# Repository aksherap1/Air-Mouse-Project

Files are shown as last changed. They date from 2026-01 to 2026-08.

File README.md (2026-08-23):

# Air Mouse Project

Screenshot 2026-01-02 at 2 03 32 PM

Screenshot 2026-08-23 at 3 50 18 PM

### About  
The Air Mouse is a wireless, motion-controlled computer mouse. Using an ESP32 microcontroller and an MPU-6050 IMU sensor, it detects hand movement and translates it into cursor movement on your computer. A push button allows for left-click functionality.  

This project demonstrates:

- Bluetooth HID communication
- Sensor integration
- Embedded programming w/Arduino IDE
- PCB Building
- Gyroscope + accelerometer processing
- Motion-controlled input devices
- Button input handling
- Real-time data processing
- Adjustable sensitivity & deadzone implementation

---

### Materials Used  

- ESP32 Nano Dev Board
- MPU-6050
- 4 Push Buttons
- Breadboard
- Jumper Wires
- USB Cable
- PCB

---

### Process

**1. Set up development environment**
- Install Arduino IDE
- Add ESP32 board support
- Install ESP32-BLE-Mouse library by T-vK

**2. Connect hardware (Breadboard)**
- Wire MPU-6050 to ESP32 via I2C (SDA -> ESP32 Nano D13, SCL -> ESP32 Nano D12, VCC -> 3.3V, GND -> GND)
- Connect push button to a digital input pin (e.g., D5, D6, D7, D8) & connect the other terminal to GND
- Use a breadboard for easy prototyping

**3. Test BLE Mouse**
- Open: File -> Examples ->ESP32 BLE Mouse -> BLE_Mouse in Arduino IDE
- Upload code via USB
- Check Bluetooth settings - ESP32 should appear as a mouse

**4. Integrate motion control**
- Read MPU-6050 values
- Map tilt and acceleration data to mouse movement commands
- Adjust sensitivity and filtering for smooth cursor movement

**5. Test clicking**
- Configure the push buttons to send left-click commands via BLE
- Verify clicking works with cursor movement

**6. Design a PCB**
- After a working breadboard prototype:
  - Draw schematic of ESP32, MPU-6050, and button
  - Designed PCB layout using KiCad
  - Order PCB
  - Solder components (ESP32 Nano module, sensor, button) onto the PCB
  - Upload same Arduino code to ESP32 module

7. Finalize device
- Add battery for wireless use
- Place all components in an enclosure for portability
- Ensure smooth movement and reliable clicking

---

### Analysis

- The MPU-6050 gyroscope and accelerometer detect the device's orientation and motion in 3D space. The accelerometer measures linear acceleration (tilt and movement), while the gyroscope measures rotational velocity. Together, they allow the ESP32 to move the mouse cursor based on how you tilt or rotate the device.
- Built-in gyro calibration establishes a baseline “neutral” position when the device is stationary. This means the system knows what counts as “no movement,” preventing the cursor from drifting due to small biases in the sensor readings.
- The moving average filter is a mathematical method to smooth out rapid fluctuations in sensor data. It averages several consecutive readings so that sudden spikes or jitters (like tiny hand tremors) do not cause erratic mouse movement.
- Adjustable deadzone defines a small range of tilt values that are ignored. Any motion inside this range is treated as zero, which prevents the cursor from moving unintentionally when the device is nearly still.
- Sensitivity determines how strongly tilt translates into cursor movement. Higher sensitivity makes the cursor move faster for a small tilt, while lower sensitivity requires more tilt for the same cursor motion.
- By combining calibration, filtering, deadzone, and adjustable sensitivity, the system achieves smooth, stable, and intuitive motion control, accurately translating intended device movements into cursor actions while ignoring unintended micro-movements.

---

### Citations

- https://github.com/udit1567/Circuit_forge/tree/main/Air%20Mouse
- https://github.com/T-vK/ESP32-BLE-Mouse

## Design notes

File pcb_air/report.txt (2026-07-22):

Info: Output directory '/Users/akshera/Downloads/Air-Mouse-Project/pcb_air/gerber' created.
Plotted to '/Users/akshera/Downloads/Air-Mouse-Project/pcb_air/gerber/pcb_air-F_Cu.gbr'.
Plotted to '/Users/akshera/Downloads/Air-Mouse-Project/pcb_air/gerber/pcb_air-B_Cu.gbr'.
Plotted to '/Users/akshera/Downloads/Air-Mouse-Project/pcb_air/gerber/pcb_air-F_Paste.gbr'.
Plotted to '/Users/akshera/Downloads/Air-Mouse-Project/pcb_air/gerber/pcb_air-B_Paste.gbr'.
Plotted to '/Users/akshera/Downloads/Air-Mouse-Project/pcb_air/gerber/pcb_air-F_Silkscreen.gbr'.
Plotted to '/Users/akshera/Downloads/Air-Mouse-Project/pcb_air/gerber/pcb_air-B_Silkscreen.gbr'.
Plotted to '/Users/akshera/Downloads/Air-Mouse-Project/pcb_air/gerber/pcb_air-F_Mask.gbr'.
Plotted to '/Users/akshera/Downloads/Air-Mouse-Project/pcb_air/gerber/pcb_air-B_Mask.gbr'.
Plotted to '/Users/akshera/Downloads/Air-Mouse-Project/pcb_air/gerber/pcb_air-Edge_Cuts.gbr'.
Created Gerber job file '/Users/akshera/Downloads/Air-Mouse-Project/pcb_air/gerber/pcb_air-job.gbrjob'.
Info: Done.
Info: Done.

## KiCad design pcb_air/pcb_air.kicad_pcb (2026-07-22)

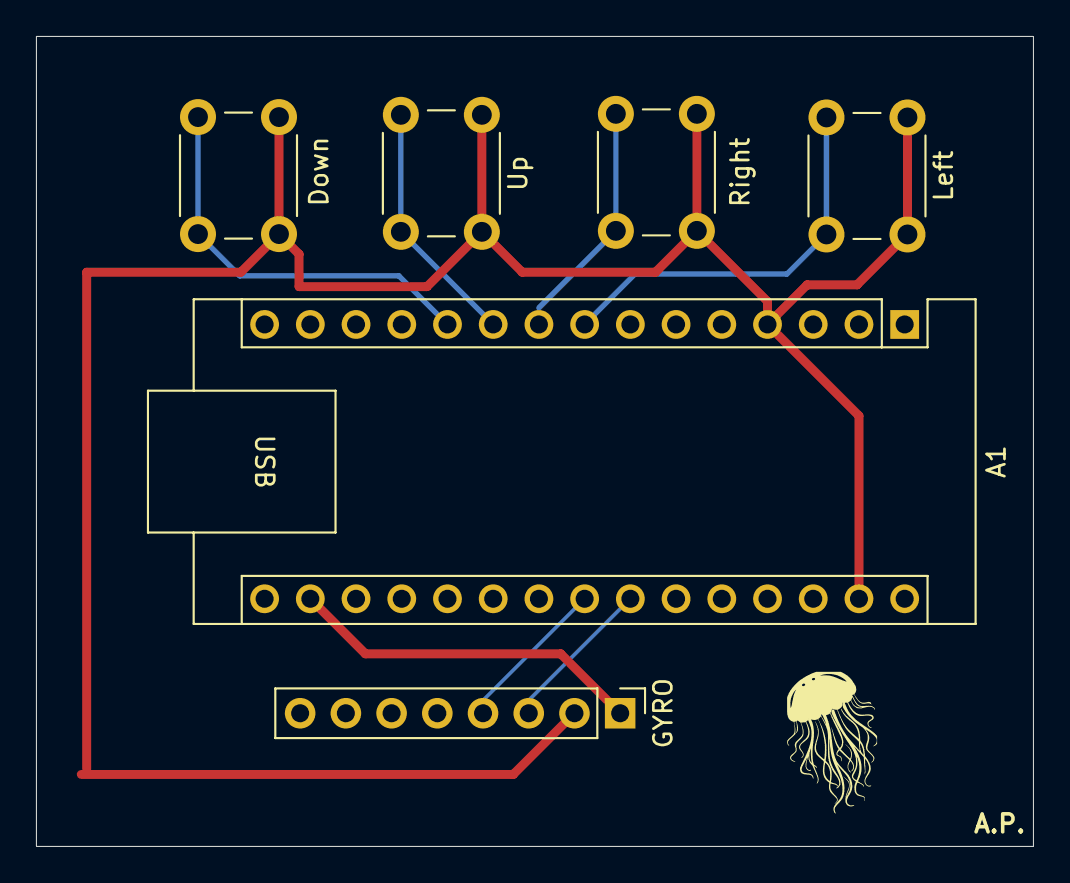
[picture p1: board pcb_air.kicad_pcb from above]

Board: 2 copper layers, 55.4 x 45.0 mm, 6 parts (0 on the bottom side), 8 nets.

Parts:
A1: Arduino_Nano_ESP32; Arduino_Nano
Down: SW_Push; SW_PUSH_6mm
GYRO: PinHeader_1x08_P2.54mm_Vertical
Left: SW_Push; SW_PUSH_6mm
Right: SW_Push; SW_PUSH_6mm
Up: SW_Push; SW_PUSH_6mm

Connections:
+3.3V: A1.17 (3V3), GYRO.1 (VCC)
GND: A1.4 (GND), A1.29 (GND), Down.1, GYRO.2 (GND), Left.1, Right.1, Up.1
unnamed: A1.8 (D5), Left.2
unnamed: A1.9 (D6), Right.2
unnamed: A1.10 (D7), Up.2
unnamed: A1.11 (D8), Down.2
unnamed: A1.24 (SCL/A5), GYRO.3 (SCL)
unnamed: A1.23 (SDA/A4), GYRO.4 (SDA)

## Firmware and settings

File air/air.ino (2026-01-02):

/*******************************************************
* Name: Akshera Paladhi
* Date: January 2, 2025
* Summary: This code turns an ESP32 into a BLE Air Mouse using 
* an MPU6050 gyroscope/accelerometer for motion control.
* 
* Features:
* - Mouse movement based on device tilt
* - Moving average filter to reduce jitter
* - Adjustable tilt sensitivity and deadzone
* - Four physical buttons:
*     - Left Click (BTN_LEFT)
*     - Right Click (BTN_RIGHT)
*     - Scroll Up (BTN_UP)
*     - Scroll Down (BTN_DOWN)
* - Gyro calibration at startup for stable control
* - Runtime MPU6050 connectivity check
* 
* Notes:
* - BLE connection must be established for mouse movement
* - TiltDeadzone and TiltScale can be adjusted to fine-tune
*   cursor behavior.
*******************************************************/

//libraries
#include <Wire.h> //communicates w/MPU6050
#include <BleMouse.h> //allows ESP32 to act as a BLE mouse 

BleMouse bleMouse; //create BLE mouse object to call methods on this to move cursor, click, or scroll

// MPU6050 I2C address
#define MPU_ADDR 0x68 //ADo pin connected to GND 

// Button pins
#define BTN_LEFT   D5 //Left click
#define BTN_RIGHT  D6 //Right click
#define BTN_UP     D7 //Scroll up
#define BTN_DOWN   D8 //Scroll Down

// Tilt configuration
const int tiltDeadzone = 500;   // neutral zone for tilt
const float tiltScale = 0.0015;  // smaller = slower/smoother movement 

// Moving average filter
const int filterSize = 5; 
int16_t axBuffer[filterSize], ayBuffer[filterSize];
int filterIndex = 0;

// Gyro calibration offsets
int16_t axOffset = 0, ayOffset = 0; //stores average resting value from MPU6050 so mouse starts neutral

// Button states for press/release logic
//keeps tracks of button press states to prevent sending multiple clicks/scrolls when holding a buttons
bool leftPressed = false;
bool rightPressed = false;
bool upPressed = false;
bool downPressed = false;

//Starts serial monitor for debugging
void setup() {
  Serial.begin(115200);
  while (!Serial);

  // Initialize buttons (sets buttons input w/internal-pull-up resistors & buttons connect to GND when pressed)
  pinMode(BTN_LEFT, INPUT_PULLUP);
  pinMode(BTN_RIGHT, INPUT_PULLUP);
  pinMode(BTN_UP, INPUT_PULLUP);
  pinMode(BTN_DOWN, INPUT_PULLUP);

  // Initialize BLE mouse
  bleMouse.begin();
  Serial.println("BLE Mouse ready");

  // Initialize I2C
  Wire.begin(13, 12); //SDA = D13, SCL = D12, at 4000kHz speed
  Wire.setClock(400000);

  // --- Check MPU6050 connection ---
  Wire.beginTransmission(MPU_ADDR);
  Wire.write(0x75); // WHO_AM_I register
  Wire.endTransmission(false);
  Wire.requestFrom((uint8_t)MPU_ADDR, (size_t)1, true); // ESP32 Nano -safe
  if (Wire.available()) {
    uint8_t whoAmI = Wire.read();
    if (whoAmI == 0x68) {
      Serial.println("MPU6050 detected successfully!");
    } else {
      Serial.print("MPU6050 WHO_AM_I mismatch: 0x");
      Serial.println(whoAmI, HEX);
    }
  } else {
    Serial.println("Error: MPU6050 not detected! Check wiring.");
  }

  // Wake up MPU6050
  Wire.beginTransmission(MPU_ADDR);
  Wire.write(0x6B);
  Wire.write(0); 
  Wire.endTransmission(true);
  Serial.println("MPU6050 initialized");

  // Initialize moving average buffers
  for (int i = 0; i < filterSize; i++) {
    axBuffer[i] = 0;
    ayBuffer[i] = 0;
  }

  // Calibrate gyro
  calibrateGyro();
}

// --- Gyro calibration ---
void calibrateGyro() {
  Serial.println("Calibrating gyro... keep device still!");
  long axSum = 0, aySum = 0;
  const int samples = 100;
  for (int i = 0; i < samples; i++) {
    int16_t ax, ay, az;
    readMPU(ax, ay, az);
    axSum += ax;
    aySum += ay;
    delay(5);
  }
  axOffset = axSum / samples;
  ayOffset = aySum / samples;
  Serial.print("Calibration complete: axOffset=");
  Serial.print(axOffset);
  Serial.print(" ayOffset=");
  Serial.println(ayOffset);
}

// --- Read raw MPU6050 values ---
void readMPU(int16_t &ax, int16_t &ay, int16_t &az) {
  Wire.beginTransmission(MPU_ADDR);
  Wire.write(0x3B); // starting register for accel
  Wire.endTransmission(false);
  Wire.requestFrom((uint8_t)MPU_ADDR, (size_t)6, true); // ESP32 Nano -safe
  ax = Wire.read() << 8 | Wire.read();
  ay = Wire.read() << 8 | Wire.read();
  az = Wire.read() << 8 | Wire.read();
}

// --- Map tilt to mouse movement with deadzone --- (possibly might have to update this part so it stays still at one point)
int mapTilt(int16_t val) {
  if (abs(val) < tiltDeadzone) return 0;
  int scaled = (int)(val * tiltScale);
  if (scaled == 0) return (val > 0 ? 1 : -1); // ensure minimum movement
  return scaled;
}


// --- Moving average filter for smooth movement ---
int filterAxis(int16_t val, int16_t *buffer) {
  buffer[filterIndex] = val;
  long sum = 0;
  for (int i = 0; i < filterSize; i++) sum += buffer[i];
  return sum / filterSize;
}

// --- Handle button clicks and scrolling ---
void handleButtons() {
  // --- Left click ---
  if (digitalRead(BTN_LEFT) == LOW) {
    if (!leftPressed) {
      bleMouse.press(MOUSE_LEFT);
      leftPressed = true;
    }
  } else if (leftPressed) {
    bleMouse.release(MOUSE_LEFT);
    leftPressed = false;
  }

  // --- Right click ---
  if (digitalRead(BTN_RIGHT) == LOW) {
    if (!rightPressed) {
      bleMouse.press(MOUSE_RIGHT);
      rightPressed = true;
    }
  } else if (rightPressed) {
    bleMouse.release(MOUSE_RIGHT);
    rightPressed = false;
  }

  // --- Scroll Up ---
  if (digitalRead(BTN_UP) == LOW) {
    if (!upPressed) {
      bleMouse.move(0, 0, 1); // scroll wheel up
      upPressed = true;
    }
  } else upPressed = false;

  // --- Scroll Down ---
  if (digitalRead(BTN_DOWN) == LOW) {
    if (!downPressed) {
      bleMouse.move(0, 1, -1); // scroll wheel down
      downPressed = true;
    }
  } else downPressed = false;
}

// --- Optional MPU6050 runtime check ---
void checkMPU() {
  Wire.beginTransmission(MPU_ADDR);
  Wire.write(0x75);
  if (Wire.endTransmission(false) != 0) {
    Serial.println("Warning: MPU6050 not responding!");
  }
}

void loop() {
  // Only move mouse if BLE is connected
  if (!bleMouse.isConnected()) return;

  // Optional runtime MPU check every loop
  checkMPU();

  int16_t ax, ay, az;
  readMPU(ax, ay, az);

  // Apply calibration offsets
  ax -= axOffset;
  ay -= ayOffset;

  // Apply moving average filter
  int filtX = filterAxis(ay, ayBuffer); // left/right
  int filtY = filterAxis(ax, axBuffer); // forward/back
  filterIndex = (filterIndex + 1) % filterSize;

  // Map to cursor movement
  int moveX = mapTilt(filtX);
  int moveY = mapTilt(filtY);

  // Limit movement to avoid huge jumps
  moveX = constrain(moveX, -5, 5);
  moveY = constrain(moveY, -5, 5);

  // Move mouse if movement exists
  if (moveX != 0 || moveY != 0) {
    bleMouse.move(moveX, moveY);
    Serial.print("Move → X: "); Serial.print(moveX);
    Serial.print(" Y: "); Serial.println(moveY);
  }

  // Handle all buttons and scroll
  handleButtons();

  delay(20); // ~50Hz update for smooth motion
}

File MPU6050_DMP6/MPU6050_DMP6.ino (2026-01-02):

/*******************************************************
* Name: Akshera Paladhi
* Date: January 2, 2025
* This code checks if MPU6050 is connected properly
*******************************************************/

#include <Wire.h>
#include <MPU6050.h>

MPU6050 mpu;

void setup() {
  Serial.begin(115200);
  while (!Serial);

  Serial.println("Starting MPU test...");

  Wire.begin(13, 12);   // SDA, SCL (ESP32-style)
  Wire.setClock(100000);

  mpu.initialize();

  if (mpu.testConnection()) {
    Serial.println("MPU6050 connected!");
  } else {
    Serial.println("MPU6050 NOT FOUND");
    while (1);
  }
}

void loop() {}
